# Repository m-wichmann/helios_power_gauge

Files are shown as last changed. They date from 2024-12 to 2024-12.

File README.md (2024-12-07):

# Helios Power Gauge
The Helios Power Gauge is a simple display of power data for the house, PV, battery and EV wallbox. The project is rather specific to this setup and is not meant to be generalised, but maybe someone still finds something useful.

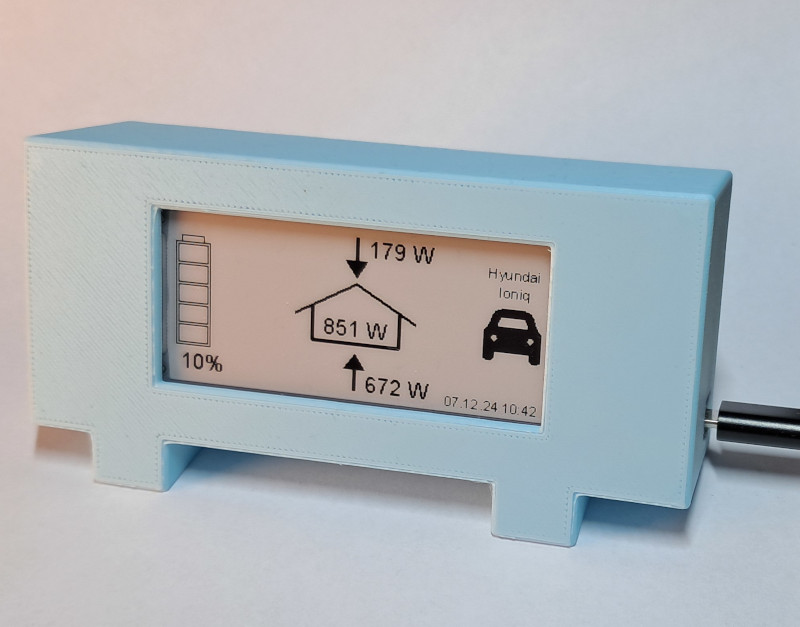
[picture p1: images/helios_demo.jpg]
Helios Power Gauge


## Software
Helios was setup on Raspberry Pi OS by copying the necessary files and setting up a systemd unit. Following steps need to be done:
* Install Raspberry Pi OS (tested with Debian 12 Bookworm)
* Activate SPI via `raspi-config`
* Setup all available WiFis: `nmtui`
* Install all requirements: `sudo apt install python3-spidev python3-pil python3-requests python3-pymodbus`
* Copy "helios.py", "arial.ttf" and "car.png" to /home/helios/
* Make script executable: `chmod a+x /home/helios/helios.py`
* Customize API keys, IPs... at the top of helios.py
* Copy "helios.service" to /etc/systemd/system/helios.service
* Activate service: `sudo systemctl enable helios`

The font "arial.ttf" is not distributed and needs to be copied from somewhere else. Or just use another font.

## Hardware
A Raspberry Pi Zero 2 W is the basis for Helios. The display is a Waveshare "2.9inch E-Paper E-Ink Display Module (B) for Raspberry Pi Pico" (see [1], [2], [3] and [4]). Following pins need to be connected between both boards:

    Display       RPi
    17 Busy <---> GPIO24 18
    16 RST  <---> GPIO17 11
    11 DC   <---> GPIO25 22
    12 CS   <---> GPIO8  24
    14 CLK  <---> GPIO11 23
    15 DIN  <---> GPIO10 19
    13 GND  <---> GND    20
    39 VCC  <---> 3V3    17

Be aware that the display contains a level shifter. The signals need to be soldered on the 3.3V side. The power suplly of the Raspberry Pi could be directly done using a USB cable. But since the case is to small to allow or normal plug I opted to solder GND and VCC of a USB cable directly to the board.

## Case
The case was designed using OnShape and the parametric design can be found [here](https://cad.onshape.com/documents/793ead52422ab2c3b7f9ba85/w/d6f01563430c41d83c825577/e/830e2b94e4fecfd9d25fe38c). The exported 3mf files are also found in this repo.

The design contains three parts. The display frame fastens the Rasperry Pi Zero and the Display together and allows the frame to be screwed to the front plate. The front plate contains practically everything else. The backlate slides into the front plate and is fixed with a screw. All screws are either M2.5 or M3 and nuts are glued in to be used as threads.

## Possible improvements
* The 2.9" (B) display is a three color variant that somehow does not like to be set in BW mode. At least I couldn't get it to work. The slow refresh time is pretty annoying. By using the normal 2.9" black and white version this would probably be faster.
* The display driver could probably be improved alot. Custom LUTs and partial refresh could result in basically flicker free refreshes (at least maybe with another display), but I just could not get it to work. Some interesting links can be found under [5], [6], [7] and [8].

## License
This project is licensed under MIT license. The image "car.png" is taken from Font Awesome.

## Links
[1] https://www.waveshare.com/wiki/Pico-ePaper-2.9-B

[2] https://www.waveshare.com/wiki/2.9inch_e-Paper_Module_(B)_Manual

[3] https://files.waveshare.com/upload/a/af/2.9inch-e-paper-b-v3-specification.pdf

[4] https://github.com/waveshareteam/e-Paper/blob/master/RaspberryPi_JetsonNano/python/lib/waveshare_epd/epd2in9b_V3.py

[5] https://github.com/adafruit/Adafruit_EPD/blob/master/src/drivers/Adafruit_UC8151D.cpp

[6] https://github.com/adafruit/Adafruit_CircuitPython_UC8151D/blob/main/adafruit_uc8151d.py

[7] https://github.com/olikraus/u8g2/issues/1393

[8] https://github.com/antirez/uc8151_micropython/

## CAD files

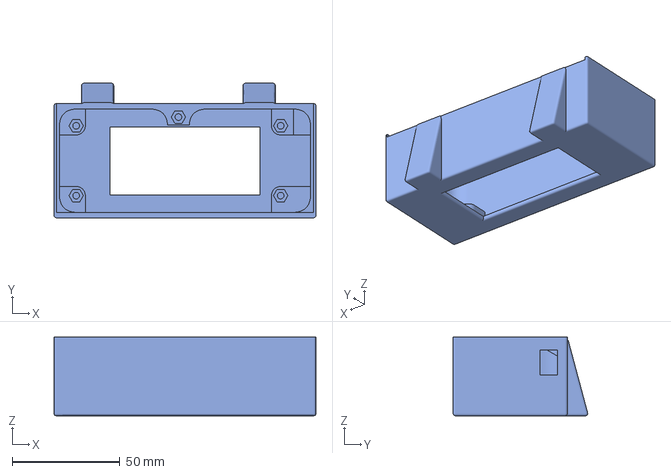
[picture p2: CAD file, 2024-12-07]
case/helios - front_plate.3mf
121.6 x 62.5 x 36.5 mm

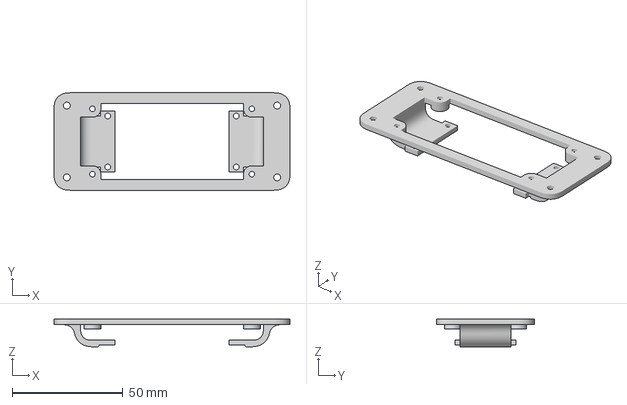
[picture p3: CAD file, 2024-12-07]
case/helios - display_frame.3mf
106.5 x 44.0 x 12.5 mm

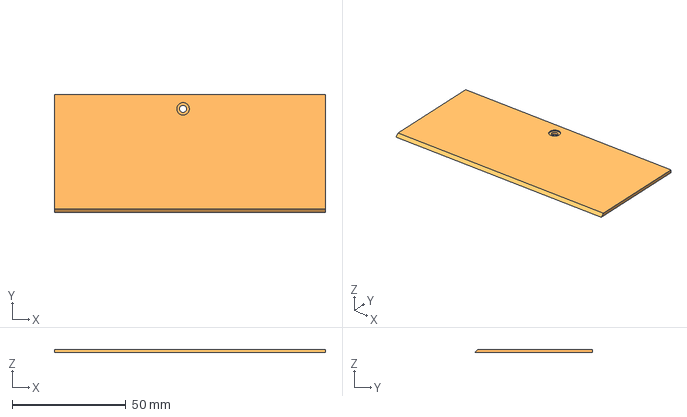
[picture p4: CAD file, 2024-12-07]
case/helios - back_plate.3mf
119.1 x 51.8 x 1.50 mm

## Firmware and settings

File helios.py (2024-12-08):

#!/usr/bin/env python3

import os
import time
import math
import datetime
import urllib.parse

import spidev
import gpiozero
from PIL import Image, ImageDraw, ImageFont

import requests
from pymodbus.client import ModbusTcpClient
from pymodbus.payload import BinaryPayloadDecoder
from pymodbus.constants import Endian


VERBOSE = False
DISPLAY_REFRESH_TIME = 10 * 60

# TODO: Add API key and site id
SOLAREDGE_API_KEY = ''
SOLAREDGE_SITE_ID = ''

# TODO: Add IP and port
CONVERTER_IP = '192.168.0.100'
CONVERTER_PORT = 502
WALLBOX_IP = '192.168.0.101'
WALLBOX_PORT = 502

# TODO: Add RFID card ids and strings
WALLBOX_RFID_CARDS = {
    
}


class Display:
    WIDTH = 296
    HEIGHT = 128

    EPD_CMD_PANEL_SETTING = 0x00
    EPD_CMD_POWER_OFF = 0x02
    EPD_CMD_POWER_ON = 0x04
    EPD_CMD_DEEP_SLEEP = 0x07
    EPD_CMD_DISPLAY_START_BW = 0x10
    EPD_CMD_DISPLAY_REFRESH = 0x12
    EPD_CMD_DISPLAY_START_R = 0x13
    EPD_CMD_VCOM_DATA_INTERVAL = 0x50
    EPD_CMD_RESOLUTION_SETTING = 0x61
    EPD_CMD_GET_STATUS = 0x71
    EPD_PARAM_DEEP_SLEEP_CHECK_CODE = 0xa5

    def __enter__(self):
        self.GPIO_RST_PIN = gpiozero.LED("GPIO17")
        self.GPIO_DC_PIN = gpiozero.LED("GPIO25")
        self.GPIO_BUSY_PIN = gpiozero.Button("GPIO24", pull_up = False)
        self.spi = spidev.SpiDev()
        self.spi.open(0, 0)
        self.spi.max_speed_hz = 4_000_000
        self.spi.mode = 0

        self._init_display()
        self.clear()
        return self

    def __exit__(self, exc_type, exc_val, exc_tb):
        self._sleep()
        self.spi.close()
        self.GPIO_RST_PIN.off()
        self.GPIO_DC_PIN.off()
        del self.spi
        del self.GPIO_RST_PIN
        del self.GPIO_DC_PIN
        del self.GPIO_BUSY_PIN
        return False

    def _set_pin_rst(self, value):
        self.GPIO_RST_PIN.on() if value else self.GPIO_RST_PIN.off()

    def _set_pin_dc(self, value):
        self.GPIO_DC_PIN.on() if value else self.GPIO_DC_PIN.off()

    def _get_pin_busy(self):
        return self.GPIO_BUSY_PIN.value

    def _spi_writebyte(self, data):
        self.spi.writebytes(data)

    def _spi_writebyte2(self, data):
        self.spi.writebytes2(data)

    def _reset(self):
        self._set_pin_rst(1)
        time.sleep(0.200)
        self._set_pin_rst(0)
        time.sleep(0.002)
        self._set_pin_rst(1)
        time.sleep(0.200)

    def _send_command(self, command):
        self._set_pin_dc(0)
        self._spi_writebyte([command])

    def _send_data(self, data):
        self._set_pin_dc(1)
        self._spi_writebyte([data])

    def _send_data2(self, data):
        self._set_pin_dc(1)
        self._spi_writebyte2(data)

    def _read_busy(self):
        self._send_command(Display.EPD_CMD_GET_STATUS)
        while self._get_pin_busy() == 0:
            self._send_command(Display.EPD_CMD_GET_STATUS)
            time.sleep(0.200)

    def _init_display(self):
        self._reset()

        self._send_command(Display.EPD_CMD_POWER_ON)
        self._read_busy()

        self._send_command(Display.EPD_CMD_PANEL_SETTING)
        self._send_data(0x8f)

        self._send_command(Display.EPD_CMD_RESOLUTION_SETTING)
        self._send_data(0x80)
        self._send_data(0x01)
        self._send_data(0x28)

        self._send_command(Display.EPD_CMD_VCOM_DATA_INTERVAL)
        self._send_data(0x77)

        self._send_command(Display.EPD_CMD_POWER_OFF)
        self._read_busy()

    def _sleep(self):
        self._send_command(Display.EPD_CMD_POWER_OFF)
        self._read_busy()
        self._send_command(Display.EPD_CMD_DEEP_SLEEP)
        self._send_data(Display.EPD_PARAM_DEEP_SLEEP_CHECK_CODE)
        time.sleep(2.000)

    def display(self, blackimage, ryimage):
        self._send_command(Display.EPD_CMD_POWER_ON)
        self._read_busy()

        if blackimage != None:
            if isinstance(blackimage, Image.Image):
                blackimage = self._getbuffer(blackimage)
            self._send_command(Display.EPD_CMD_DISPLAY_START_BW)
            self._send_data2(blackimage)

        if ryimage != None:
            if isinstance(ryimage, Image.Image):
                ryimage = self._getbuffer(ryimage)
            self._send_command(Display.EPD_CMD_DISPLAY_START_R)
            self._send_data2(ryimage)

        self._send_command(Display.EPD_CMD_DISPLAY_REFRESH)
        time.sleep(0.200)
        self._read_busy()

        self._send_command(Display.EPD_CMD_POWER_OFF)
        self._read_busy()

    def clear(self):
        self.display([0xff] * int(Display.WIDTH * Display.HEIGHT / 8), [0xff] * int(Display.WIDTH * Display.HEIGHT / 8))

    def _getbuffer(self, image):
        """Transpose image data. PIL image uses 0,0 for top left corner with direct pixel access. The display uses
        8 Pixel per byte, with the first pixel beeing the top bit of the first byte and the top right corner of the
        display. The pixels are drawn by cols from top-right to bottom-right, ending bottom-left with the last pixel."""
        buf = [0xFF] * (int(Display.WIDTH/8) * Display.HEIGHT)
        image_monocolor = image.convert('1')
        imwidth, imheight = image_monocolor.size
        pixels = image_monocolor.load()
        for x in range(imwidth):
            for y in range(imheight):
                if pixels[x, y] == 0:
                    x_dst = imwidth - x - 1
                    buf[x_dst * (Display.HEIGHT // 8) + (y // 8)] &= ~(0x80 >> (y % 8))
        return buf


class Designer:
    FONT_PATH = 'arial.ttf'
    RESSOURCE_DIR = os.path.dirname(os.path.realpath(__file__))

    def __init__(self, display):
        self.display = display
        self.font = ImageFont.truetype(os.path.join(Designer.RESSOURCE_DIR, Designer.FONT_PATH), 18)
        self.font_small = ImageFont.truetype(os.path.join(Designer.RESSOURCE_DIR, Designer.FONT_PATH), 11)

    def _draw_battery(self, state):
        self.draw.rectangle((1+5, 15, 29-5, 20), fill=1, outline=0)
        self.draw.rectangle((1, 20, 29, 102), fill=1, outline=0)
        self.draw.rectangle((3, 22+2*0+14*0, 27, 22+2*0+14*1), fill=0 if state > 90 else 1, outline=0)
        self.draw.rectangle((3, 22+2*1+14*1, 27, 22+2*1+14*2), fill=0 if state > 70 else 1, outline=0)
        self.draw.rectangle((3, 22+2*2+14*2, 27, 22+2*2+14*3), fill=0 if state > 50 else 1, outline=0)
        self.draw.rectangle((3, 22+2*3+14*3, 27, 22+2*3+14*4), fill=0 if state > 30 else 1, outline=0)
        self.draw.rectangle((3, 22+2*4+14*4, 27, 22+2*4+14*5), fill=0 if state > 10 else 1, outline=0)
        self.draw.text((5, 105), f'{state:2.0f}%', font=self.font, fill=0)

    def _draw_house(self, state):
        w = 35
        d = 15
        lt = (self.display.WIDTH/2-w, 60)
        rt = (self.display.WIDTH/2+w, 60)
        lb = (self.display.WIDTH/2-w, 87)
        rb = (self.display.WIDTH/2+w, 87)
        top = (self.display.WIDTH/2, 40)
        text = (self.display.WIDTH/2, 75)

        self.draw.line((lt, lb), fill=0, width=3)
        self.draw.line((lb, rb), fill=0, width=3)
        self.draw.line((rt, rb), fill=0, width=3)

        base_turn = math.degrees(math.atan2(lt[1] - top[1], lt[0] - top[0]))
        temp_x = lt[0] + d * math.cos(math.radians(base_turn))
        temp_y = lt[1] + d * math.sin(math.radians(base_turn))
        self.draw.line(((temp_x, temp_y), (top[0], top[1])), fill=0, width=3)

        base_turn = math.degrees(math.atan2(rt[1] - top[1], rt[0] - top[0]))
        temp_x = rt[0] + d * math.cos(math.radians(base_turn))
        temp_y = rt[1] + d * math.sin(math.radians(base_turn))
        self.draw.line(((temp_x, temp_y), (top[0], top[1])), fill=0, width=3)

        self.draw.text(text, f'{format_measurement(state, "W")}', font=self.font, fill=0, anchor='mm')

    def _draw_car(self, type_str):
        if type_str:
            self.image_buffer.paste(Image.open('car.png'), (250, 45))
            self.draw.text((252, 15), type_str, font=self.font_small, fill=0)

    def _draw_arrow(self, coord0, coord1, invert=False, draw_head=True):
        d = 15
        angle = 35

        if invert:
            coord1, coord0 = coord0, coord1

        base_turn = math.degrees(math.atan2(coord1[1] - coord0[1], coord1[0] - coord0[0]))
        x1_back = coord1[0] + (d*0.8) * math.cos(math.radians(base_turn + 180))
        y1_back = coord1[1] + (d*0.8) * math.sin(math.radians(base_turn + 180))
        x1_top = coord1[0] + d * math.cos(math.radians(base_turn + 180 + angle))
        y1_top = coord1[1] + d * math.sin(math.radians(base_turn + 180 + angle))
        x1_bot = coord1[0] + d * math.cos(math.radians(base_turn + 180 - angle))
        y1_bot = coord1[1] + d * math.sin(math.radians(base_turn + 180 - angle))

        if draw_head:
            self.draw.line(((coord0[0], coord0[1]), (x1_back, y1_back)), fill=0, width=3)
            self.draw.polygon(((coord1[0], coord1[1]), (x1_top, y1_top), (x1_bot, y1_bot)), fill=0, outline=0)
        else:
            self.draw.line(((coord0[0], coord0[1]), (coord1[0], coord1[1])), fill=0, width=3)

    def _draw_timestamp(self):
        self.draw.text((296, 128), f'{datetime.datetime.now().strftime("%d.%m.%y %H:%M")}', font=self.font_small, anchor='rb', fill=0)

    def _draw_labels(self, p_bat, p_pv, p_grid, p_car):
        if p_bat: self.draw.text((40, 75), f'{format_measurement(p_bat, "W")}', font=self.font, fill=0)
        if p_pv: self.draw.text((157, 2), f'{format_measurement(p_pv, "W")}', font=self.font, fill=0)
        if p_grid: self.draw.text((157, 108), f'{format_measurement(p_grid, "W")}', font=self.font, fill=0)
        if p_car: self.draw.text((193, 75), f'{format_measurement(p_car, "W")}', font=self.font, fill=0)

    def draw_data(self, data):
        if VERBOSE:
            print(data)

        self.image_buffer = Image.new(mode='1', size=(self.display.WIDTH, self.display.HEIGHT), color=1)
        self.draw = ImageDraw.Draw(self.image_buffer)

        self._draw_battery(data.battery_charge_level)
        self._draw_house(data.power_use) # includes data.active_poper from charging station

        # set car name to be displayed depending on RFID data
        car_name = WALLBOX_RFID_CARDS.get(data.rfid_card, '')
        self._draw_car(car_name)

        # switch arrow direction to battery depending on charging status
        if data.battery_charge_status == 'Discharging':
            self._draw_arrow((35, 64), (90, 64))
        elif data.battery_charge_status == 'Charging':
            self._draw_arrow((90, 64), (35, 64))
        elif data.battery_charge_status == 'Idle':
            # do not draw arrow if battery is neither charging nor discharging
            pass

        # draw arrow from PV only when energy is supplied
        if data.power_from_pv:
            self._draw_arrow((self.display.WIDTH/2, 4), (self.display.WIDTH/2, 35))

        # draw arrow to charging station only when car is charging
        if data.charging_status == 3:
            self._draw_arrow((205, 64), (245, 64))

        # check whether grid is supplying power or energy is fed back into the grid
        if data.power_from_grid - data.power_feed_in > 0:
            self._draw_arrow((self.display.WIDTH/2, 124), (self.display.WIDTH/2, 95))
            grid_power_flow = data.power_from_grid - data.power_feed_in
        else:
            self._draw_arrow((self.display.WIDTH/2, 95), (self.display.WIDTH/2, 124))
            grid_power_flow = data.power_feed_in - data.power_from_grid

        self._draw_labels(data.battery_charge_power, data.power_from_pv, grid_power_flow, data.active_power)

        self._draw_timestamp()

        if VERBOSE:
            self.image_buffer.save('helios_output.png')

        self.display.display(self.image_buffer, None)


class ModbusConnection:
    """
    Context manager for Modbus connection

    Stolen from: https://gist.github.com/wcheek/35599f2db14592129c358f3b35988d16
    """
    def __init__(self, host, port):
        self.host = host
        self.port = port
        self.client = None

    def __enter__(self):
        self.client = ModbusTcpClient(host=self.host, port=self.port)
        self.client.connect()
        return self.client

    def __exit__(self, exc_type, exc_val, exc_tb):
        if self.client:
            self.client.close()
        return False


class HeliosException(Exception):
    """Custom exception for Helios Power Gauge."""


def read_data_from_charging_station_via_modbus():
    """
    Read all necessary data points from the wallbox by ModbusTCP.

    References:
     - Modbus addresses for wallbox:
       https://www.keba.com/download/x/dea7ae6b84/kecontactp30modbustcp_pgen.pdf
    """
    with ModbusConnection(host=WALLBOX_IP, port=WALLBOX_PORT) as client:
        # read charging status
        result = client.read_holding_registers(address=1000, count=1)
        charging_status = BinaryPayloadDecoder.fromRegisters(result.registers, byteorder=Endian.Big).decode_32bit_uint()
        # read total energy (register contains the total energy consumption in 0.1 watt-hours)
        result = client.read_holding_registers(address=1036, count=1)
        total_energy = BinaryPayloadDecoder.fromRegisters(result.registers, byteorder=Endian.Big).decode_32bit_uint() / 10000
        # read active power (register contains the active power in milliwatts)
        result = client.read_holding_registers(address=1020, count=1)
        active_power = BinaryPayloadDecoder.fromRegisters(result.registers, byteorder=Endian.Big).decode_32bit_uint() / 1000
        # read RFID card number
        result = client.read_holding_registers(address=1500, count=1)
        rfid_card = BinaryPayloadDecoder.fromRegisters(result.registers, byteorder=Endian.Big).decode_32bit_uint()
        # read charged energy (register contains the transferred energy of the current session in 0.1 watt-hours)
        #result = client.read_holding_registers(address=1502, count=1)
        #charged_energy = BinaryPayloadDecoder.fromRegisters(result.registers, byteorder=Endian.BIG).decode_32bit_uint() / 10000
        #print(f'Charged energy in current session: {charged_energy} kWh')
    return charging_status, total_energy, active_power, rfid_card


def read_data_from_converter_via_modbus():
    """
    Read all necessary data points from the converter by ModbusTCP.

    References:
     - Modbus addresses for inverter:
       https://knowledge-center.solaredge.com/sites/kc/files/sunspec-implementation-technical-note.pdf
     - Decoding of values with BinaryPayloadDecoder:
       https://pymodbus.readthedocs.io/en/latest/source/library/pymodbus.html#pymodbus.payload.BinaryPayloadDecoder
    """
    with ModbusConnection(host=CONVERTER_IP, port=CONVERTER_PORT) as client:
        # read current AC power from converter
        result = client.read_holding_registers(address=40083, count=2)
        ac_power_used_value = BinaryPayloadDecoder.fromRegisters([result.registers[0]], byteorder=Endian.Big).decode_16bit_int()
        ac_power_used_scale_factor = BinaryPayloadDecoder.fromRegisters([result.registers[1]], byteorder=Endian.Big).decode_16bit_int()
        power_use = ac_power_used_value * pow(10, ac_power_used_scale_factor)
    battery_charge_level = 0
    battery_charge_status = 'Unknown'
    battery_charge_power = 0
    power_from_grid = 0
    power_from_pv = 0
    power_self_consumption = 0
    power_feed_in = 0
    return battery_charge_level, battery_charge_status, battery_charge_power, power_use, power_from_grid, power_from_pv, power_self_consumption, power_feed_in


def read_power_flow_data_from_api(api_key, site_id):
    """Reads all power flow values from the SolarEdge API."""
    url = f'https://monitoringapi.solaredge.com/site/{site_id}/currentPowerFlow?api_key={api_key}'
    response = requests.get(url, timeout=5)
    if response.status_code != 200:
        print(f'Error: {response}')
        raise HeliosException('Error reading data from SolarEdge API')
    data = response.json()['siteCurrentPowerFlow']
    scaling_factor = 1000 if data['unit'] == 'kW' else 1
    battery_charge_level = data['STORAGE']['chargeLevel']
    battery_charge_status = data['STORAGE']['status']
    battery_charge_power = float(data['STORAGE']['currentPower']) * scaling_factor
    return battery_charge_level, battery_charge_status, battery_charge_power


def read_power_details_data_from_api(api_key, site_id):
    """
    Reads all power values as median over the last 15 minutes from the
    SolarEdge API.
    """
    # build URL for API request
    now = datetime.datetime.now()
    fifteen_minutes_ago = now - datetime.timedelta(minutes=15)
    start_time = fifteen_minutes_ago.strftime('%Y-%m-%d %H:%M:%S')
    end_time = now.strftime('%Y-%m-%d %H:%M:%S')
    start_time_url = urllib.parse.quote(start_time, safe='/', encoding=None, errors=None)
    end_time_url = urllib.parse.quote(end_time, safe='/', encoding=None, errors=None)
    url = f'https://monitoringapi.solaredge.com/site/{site_id}/powerDetails?startTime={start_time_url}&endTime={end_time_url}&api_key={api_key}'
    response = requests.get(url, timeout=5)
    if response.status_code != 200:
        print(f'Error: {response}')
        raise HeliosException('Error reading data from SolarEdge API')
    # extract power values from response
    data = response.json()
    scaling_factor = 1000 if data['powerDetails']['unit'] == 'kW' else 1
    power_production_15m = 0
    power_consumption_15m = 0
    power_purchased_15m = 0
    power_self_consumption_15m = 0
    power_feed_in_15m = 0
    for meter in data['powerDetails']['meters']:
        try:
            # check if last measurement contains no actual value...
            if 'value' not in meter['values'][-1]:
                # ...and delete last element if that's true
                del meter['values'][-1]
            if meter['type'] == 'Production':
                power_production_15m = float(meter['values'][-1]['value']) * scaling_factor
            elif meter['type'] == 'Consumption':
                power_consumption_15m = float(meter['values'][-1]['value']) * scaling_factor
            elif meter['type'] == 'SelfConsumption':
                power_self_consumption_15m = float(meter['values'][-1]['value']) * scaling_factor
            elif meter['type'] == 'FeedIn':
                power_feed_in_15m = float(meter['values'][-1]['value']) * scaling_factor
            elif meter['type'] == 'Purchased':
                power_purchased_15m = float(meter['values'][-1]['value']) * scaling_factor
        except KeyError:
            pass
    return power_consumption_15m, power_purchased_15m, power_production_15m, power_self_consumption_15m, power_feed_in_15m


def read_data_from_converter_via_api():
    """
    Read all necessary data points from the SolarEdge API.

    Important: The SolarEdge API is rate-limited to 300 requests per day.

    References:
     - API documentation:
       https://www.solaredge.com/sites/default/files/se_monitoring_api.pdf
       https://developers.solaredge.com/docs/monitoring/e9nwvc91l1jf5-getting-started-with-monitoring-api
    """
    battery_charge_level, battery_charge_status, battery_charge_power = read_power_flow_data_from_api(SOLAREDGE_API_KEY, SOLAREDGE_SITE_ID)
    power_consumption_15m, power_purchased_15m, power_production_15m, power_self_consumption_15m, power_feed_in_15m = read_power_details_data_from_api(SOLAREDGE_API_KEY, SOLAREDGE_SITE_ID)
    return battery_charge_level, battery_charge_status, battery_charge_power, power_consumption_15m, power_purchased_15m, power_production_15m, power_self_consumption_15m, power_feed_in_15m


def format_measurement(value, unit):
    """
    Formats a measurement value with the correct unit and always 3 significant
    places depending on the magnitude of the value.
    """
    if not value:
        return f'0 {unit}'
    elif unit == 'kWh':
        return f'{value:.0f} {unit}'
    elif unit == '%':
        return f'{value:.0f} {unit}'
    else:
        try:
            magnitude = int(math.floor(math.log10(abs(float(value)))))
            match magnitude:
                case 0: return f'{value:.0f} {unit}'
                case 1: return f'{value:.0f} {unit}'
                case 2: return f'{value:.0f} {unit}'
                case 3: return f'{value/1000:.1f} k{unit}'
                case 4: return f'{value/1000:.0f} k{unit}'
                case 5: return f'{value/1000:.0f} k{unit}'
                case _: return f'{value:.1f} {unit}'
        except ValueError:
            return f'{value} {unit}'
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
